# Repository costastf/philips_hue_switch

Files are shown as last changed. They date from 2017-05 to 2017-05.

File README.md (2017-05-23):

# Philips hue switch
Micropython code that toggles a philips hue lamp using wemos d1 mini or esp8266-01s

This project is to be used with a hardware switch making that existing wall
switch not cutting the power off but using the api to toggle the lamp's
state.

Some electrical assembly required :)

# WARNING
Only mess with high current if you really really know what you are doing. If
not certified to do so please refrain from it. It can definitely kill you,
which is not a desired outcome for any hobby project.

# Problem statement
Philips hue lamps are amazing, providing a wonderful solution for home
lighting. The only problem is that the way they are operated leaves some
things to be desired.

When the traditional switch is off the lamps of course
can not be operated through the app, but only using the app is not realistic
for all lights and all conditions. Also people coming over do not have access
to the app and many people in a house create confusion.

The current solution is to purchase a separate wireless switch from
Philips to use with the lamps but that can get really expensive really quick
if you want one for each lamp and of course that does not solve the
problem of the traditional switches that either will disrupt the usage of
the lights or have to be taken out. Not fun.

# Solution
All lights can be operated through the api provided by the hue bridge.
Instead of using the switch to cut the power to the lamp leaving it useless,
we rewire the lamp to be constantly powered and the switch to an esp8266-01s
board to toggle the lamp through the api. That way our switch works as before
for all, toggling the state of the lamp and the lamp continues to be
accessible through the app all the time. Sweet right?

so we want to go from this initial state:

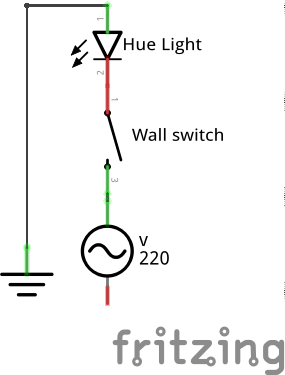
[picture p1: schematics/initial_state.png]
Initial state schematic


to this state (schematic depicting an esp01s):

![alt text](schematics/esp8266_01s_schem.png "esp01s
schematic")

# Requirements
[Enable hue api access to your bridge](https://www.developers.meethue.com/documentation/getting-started)

If project is based on a wemos D1 mini

* [wemos d1 mini](https://www.aliexpress.com/item/D1-mini-Mini-NodeMcu-4M-bytes-Lua-WIFI-Internet-of-Things-development-board-based-ESP8266-by/32644199530.html)

* [220v to 5v power converter](https://www.aliexpress.com/item/5V-700mA-3-5W-AC-DC-Precision-Buck-Converter-AC-220v-to-5v-DC-step-down/32649591757.html)

If project is based on an esp8266 01s (Current documentation mentions this case.)

* [esp8266-01s](https://www.aliexpress.com/item/New-Version-ESP8266-ESP-01-ESP01-Serial-Wireless-WIFI-Module-Transceiver-Receiver-Board-for-Internet-of/32799606069.html)

* [220v to 3.3v power converter](https://www.aliexpress.com/item/AC-220-V-to-3-3-V-DC-power-supply-module-transformer-module-is-completely-isolated/32768604824.html)

* 2x 10KΩ Resistance

# Physical Connection

You can see pictures of the connectivity under the [images](images) directory.

# Schematics

Images in png format and a fritzing project for each case can be found under 
[schematics](schematics).

# Configuration

 Rename configuration_sample.json to configuration.json and edit accordingly.
 If the board used is a wemos D1 mini the pin should be set to gpio3 (D0) 
 whereas if the board used is the esp8266-01s the pin should be set to 3 (RX)
  Everything else should just work out of the box.

# Flashing micropython

To load this project the microcontroler needs to be running micropython and you
need [ampy](https://github.com/adafruit/ampy)

Required tools:

# esp8266-01s specific

To flash the esp8266-01s a component to connect it to usb is required.
Remember that it is 3.3v power and *will* fry with 5v.

* [esp8266-01s programmer](https://www.aliexpress.com/item/ESP01-Programmer-Adapter-UART-GPIO0-ESP-01-Adaptaterr-ESP8266-USB-to-ESP8266-Serial-Wireless-Wifi/32704996344.html)

In order for the board to be flashed it has to be booted up with d0 pulled
low. That means that when the board is booted d0 should be connected to
ground.

The easiest way to do that is to stick a thin cable in the
appropriate holes as can be seen [here](images/IMG_20170519_095341.jpg). This
 of course can get pretty old pretty quick if you have a few boards to flash.

  A better solution is to add a jumper between ground and d0 as can be seen
  [here](images/IMG_20170518_141529.jpg) and [here](images/IMG_20170518_165919.jpg)
and choose the appropriate mode of booting by using the jumper cap or not.

Of course in order for the project to work properly when used the esp8266-01s
 has to be booted with d0 and d1 high, so it does not enter in flash mode.

 In order to fix this a 10K pull up resistor has to be connected between d0
 and VCC (3.3v) and between d1 and VCC so the pins are kept high and the 
 board boots into running mode even if rebooted.In order to not make the 
 board unflashable by permanent pull ups I have installed jumpers on the pull
  ups so the board can boot into flash but also be able to be programmed. Images
   of this connection can be found under [images](images) and the final end 
   result with the two pull ups installed is [this](images/IMG_20170522_210237.jpg)

 In order for the switch to not interfere with the booting process we are 
 using RX (gpio03) as input pulled high through software. That of course will
  interfere with the serial console so depending on the state of the switch 
  when the board boots you might not have access to the serial console.

# common for both wemos d1 mini and esp8266-01s
   [esptool](https://github.com/espressif/esptool) (Follow installation instructions)

  With the board connected to a usb port of your linux box assuming that the
  port is ttyUSB0 (check with dmesg after connecting to see what is assigned)

  After the first command you might have to reboot the board, or just
  disconnect and connect again.

    esptool.py --port /dev/ttyUSB0 erase_flash
    esptool.py --port /dev/ttyUSB0 --baud 460800 write_flash --flash_size=detect 0 MICROPYTHON_FIRMWARE_FOR_ESP8266.bin

  I have had some wemos d1 mini boards having trouble flashing with the above
  with garbage on the serial and the led staying on. On those boards this
  command works.

    esptool.py --port /dev/ttyUSB0 write_flash -fm dio -fs 32m 0 MICROPYTHON_FIRMWARE_FOR_ESP8266.bin

# Loading the project

Required tools:

   [ampy](https://github.com/adafruit/ampy) (Follow installation instructions)

    export AMPY_PORT=/dev/ttyUSB0
    ampy put library
    ampy put configuration.json
    ampy put main.py
    ampy put boot.py

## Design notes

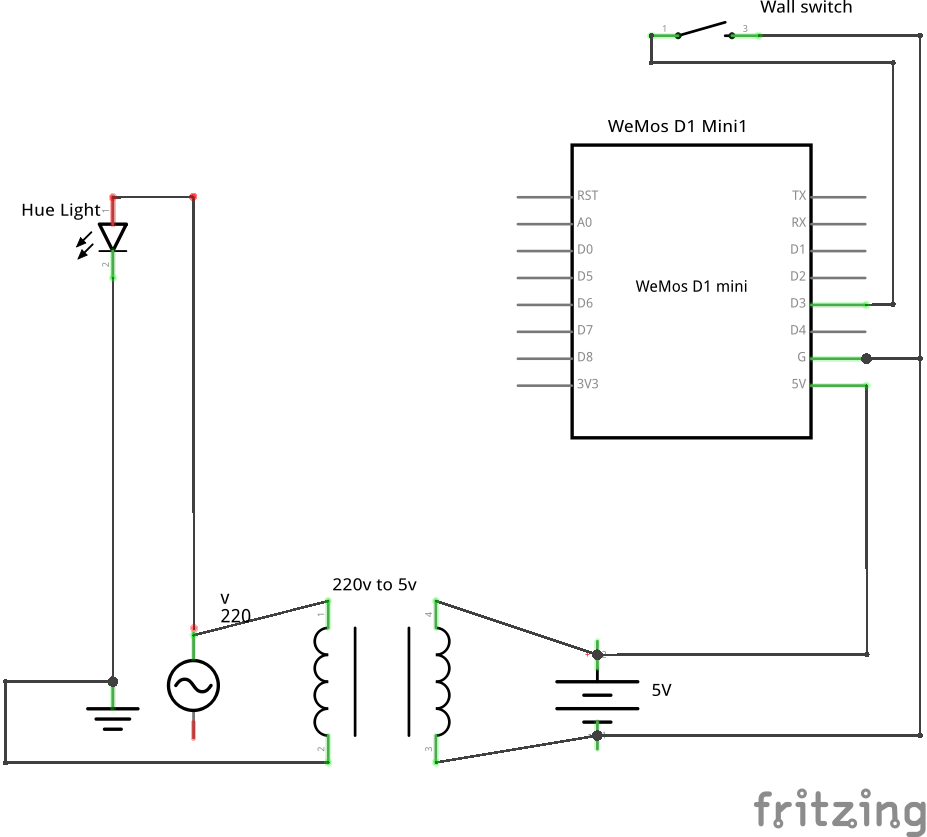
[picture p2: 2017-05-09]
schematics/final_state_with_wemos_d1_mini.png

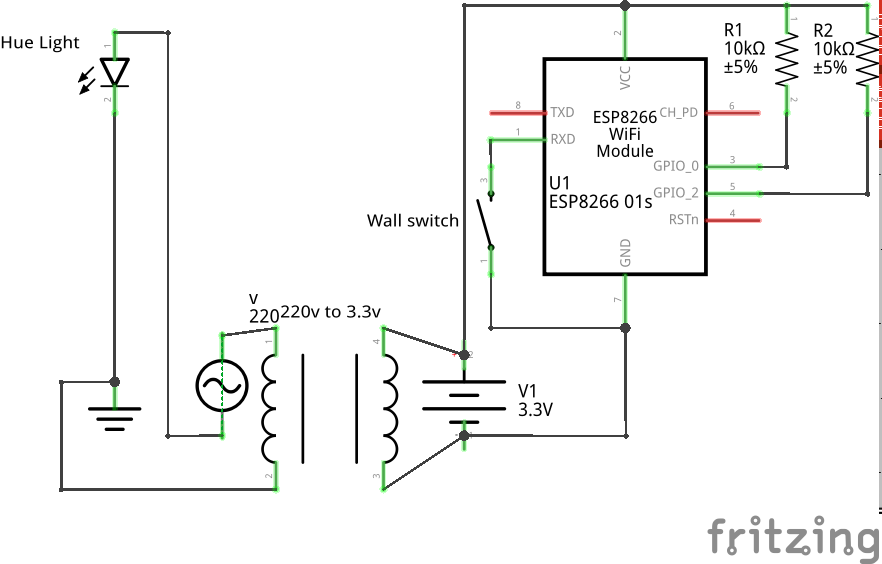
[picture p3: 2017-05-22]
schematics/esp8266_01s_schem.png

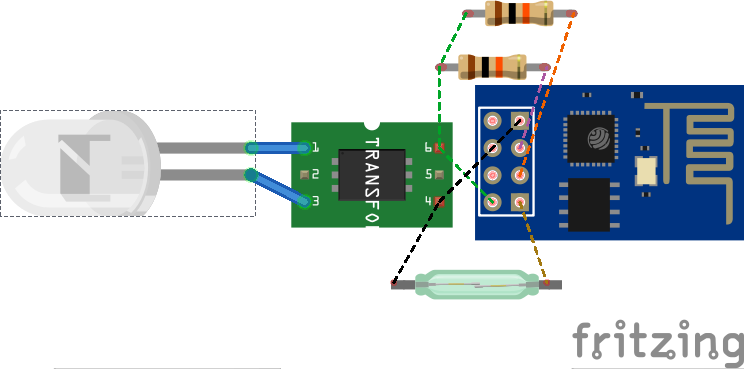
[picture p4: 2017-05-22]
schematics/esp8266_01s_bb.png

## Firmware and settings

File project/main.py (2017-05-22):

# -*- coding: utf-8 -*-
# Micropython code to toggle philips hue lamp through an esp8266
# Copyright (C) 2017  Costas Tyfoxylos
#
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
exception_timeout = configuration.get('exception_reset_timeout')


def get_switch():
    try:
        pin_number = configuration.get('pin_number')
        pin_supports_pull_up = configuration.get('pin_supports_pull_up')
        args = [pin_number, Pin.IN]
        kwargs = {}
        if pin_supports_pull_up:
            kwargs.update({'pull': Pin.PULL_UP})
        pin = Pin(*args, **kwargs)
        return pin
    except Exception as e:
        print(('Caught exception, {}'
               'resetting in {} seconds...').format(e, exception_timeout))
        time.sleep(exception_timeout)
        machine.reset()


def main():
    try:
        bridge_ip = configuration.get('hue_bridge_ip')
        token = configuration.get('hue_user_token')
        name = configuration.get('lamp_name')

        lamp = Lamp(bridge_ip, token, name)
        switch = get_switch()
        initial_state = switch.value()
        print('Current switch state is {}'.format(initial_state))
        while True:
            try:
                current_state = switch.value()
                if not current_state == initial_state:
                    lamp.toggle()
                    initial_state = current_state
                    print('Current switch state is {}'.format(initial_state))
                time.sleep_ms(300)
            except Exception as e:
                print(('Caught exception {exception}, waiting {timeout} '
                       'seconds').format(exception=e,
                                         timeout=exception_timeout))
                time.sleep(exception_timeout)
    except Exception as e:
        print(('Caught exception, {}'
               'resetting in {} seconds...').format(e, exception_timeout))
        time.sleep(exception_timeout)
        machine.reset()


if __name__ == '__main__':
    main()

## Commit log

2017-05-09 restored repo
    [wemos_d1_mini.fzz]
2017-05-19 extended network connection code to newer standard. Added esp01s fritzing schematics.
    [esp8266_01s.fzz]
2017-05-22 using RX as input pin so it does not interfere with the booting process
    [esp8266_01s.fzz]
2017-05-22 updated schematics and documentation
    [esp8266_01s.fzz]

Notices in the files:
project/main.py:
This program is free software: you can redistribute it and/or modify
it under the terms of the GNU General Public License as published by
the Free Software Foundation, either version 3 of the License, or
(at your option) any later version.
